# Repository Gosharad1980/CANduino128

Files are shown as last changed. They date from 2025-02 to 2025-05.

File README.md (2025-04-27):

# CANduino128
	- Break-out board pour la carte Olimex AVR-H128-CAN
	- Carte sur base d'AVR AT90CAN128
		- PC104 form factor
		- CAN network
		- SPI
		- I2C
		- bus d'addresse/Data externe via 74AHC373

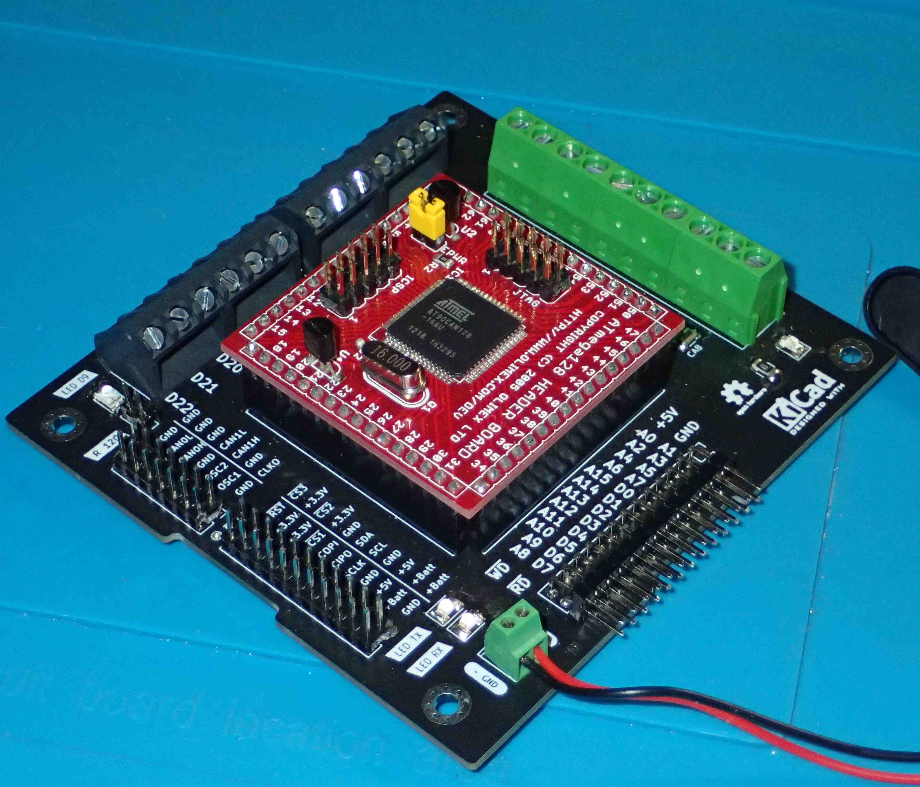
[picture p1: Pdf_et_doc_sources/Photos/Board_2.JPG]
Board 3/4


# Board details
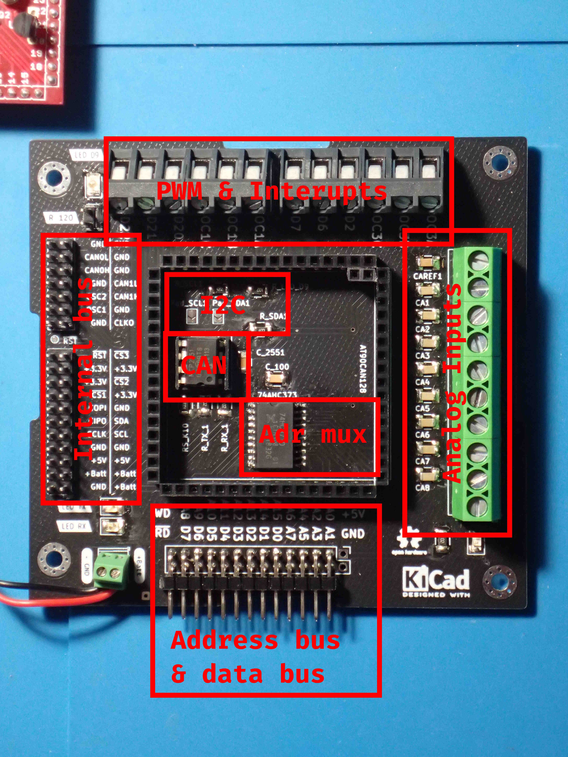
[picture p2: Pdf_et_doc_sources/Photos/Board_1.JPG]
Board details


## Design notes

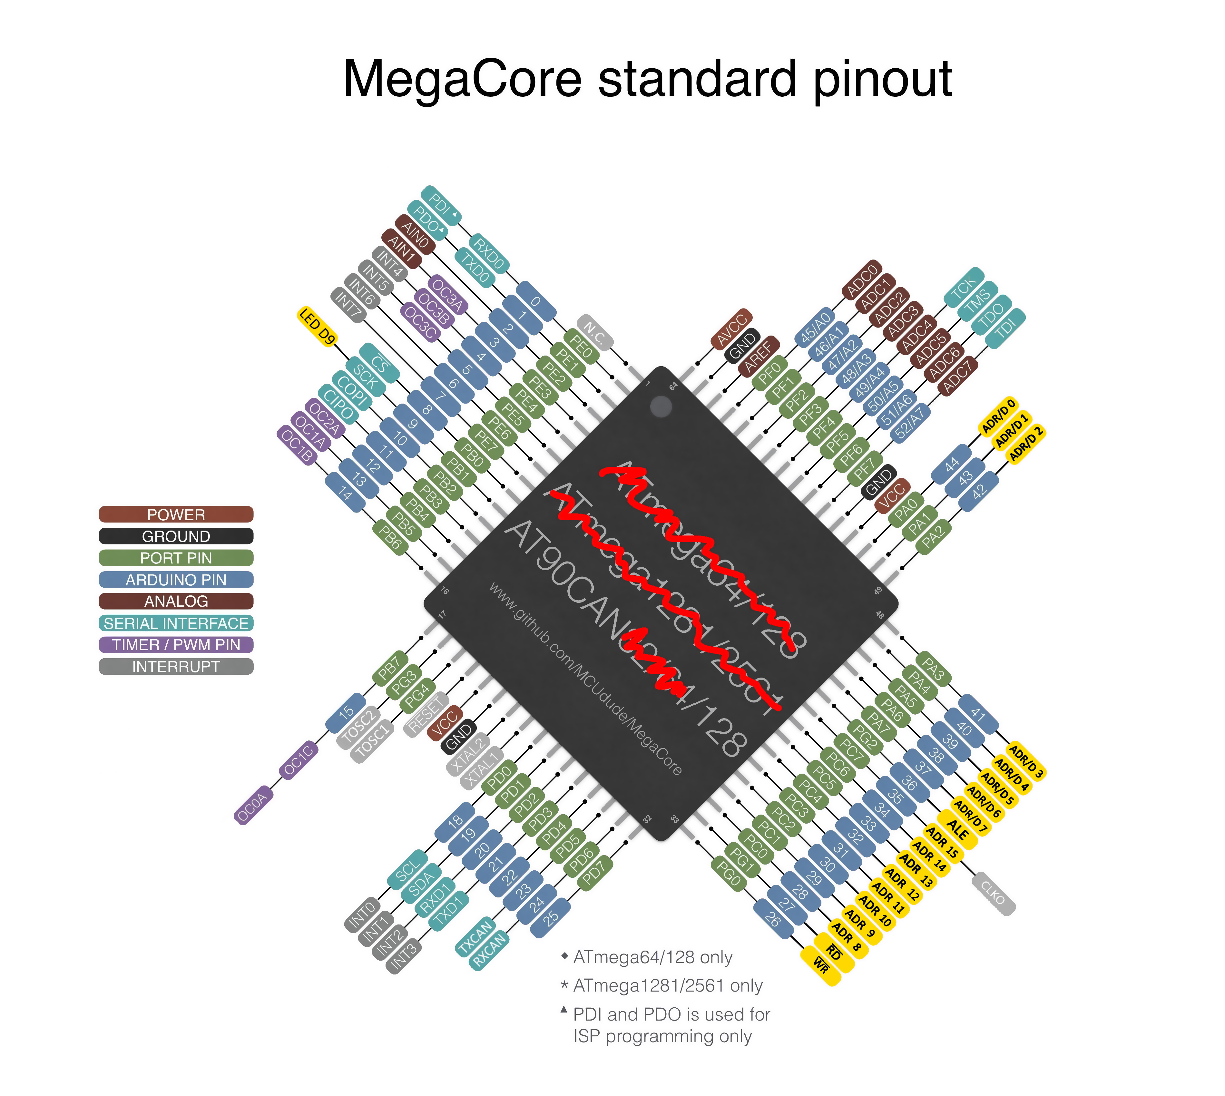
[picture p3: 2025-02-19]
Pdf_et_doc_sources/AT90CANxxx - MegaCore PinOut.jpg

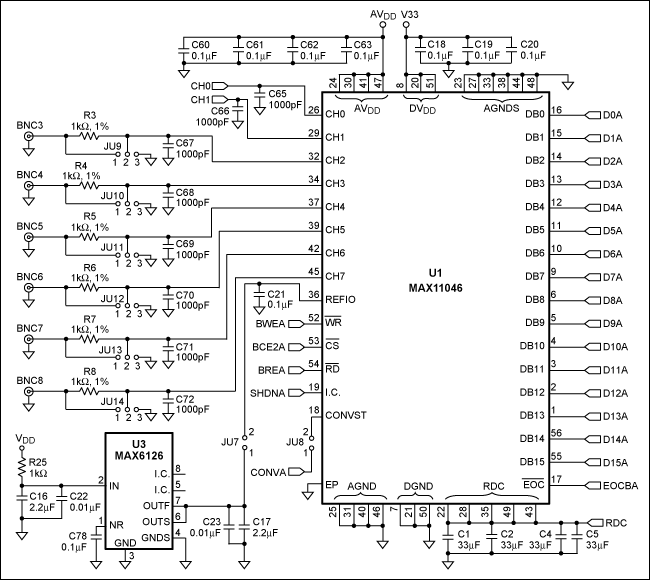
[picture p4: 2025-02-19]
Pdf_et_doc_sources/AT90CAN128 - Application Notes/4359Fig06.gif

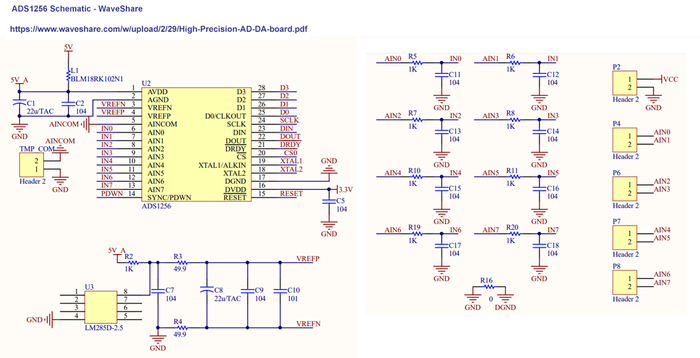
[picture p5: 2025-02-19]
Pdf_et_doc_sources/AT90CAN128 - Application Notes/s3Iia.png

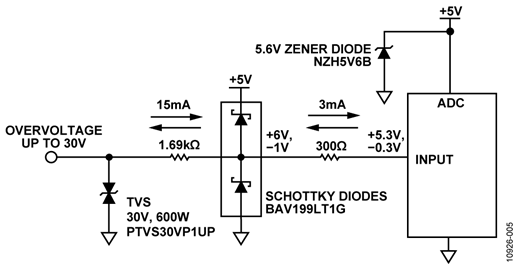
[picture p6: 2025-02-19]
Pdf_et_doc_sources/AT90CAN128 - Application Notes/m8xca9ZTZHjG40SwLESFxN0b7EQkneq3GQtdkflvBjM.png

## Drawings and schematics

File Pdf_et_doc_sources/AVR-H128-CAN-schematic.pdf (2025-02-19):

# Q1 Q²

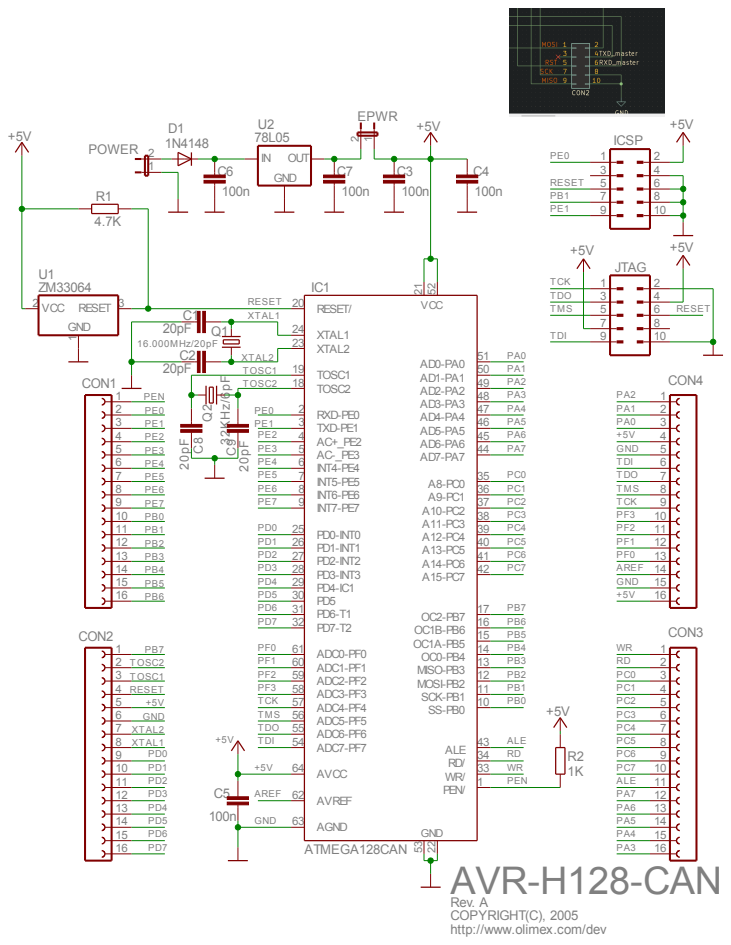
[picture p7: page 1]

Rev. A
COPYRIGHT(C), 2005
http://www.olimex.com/dev

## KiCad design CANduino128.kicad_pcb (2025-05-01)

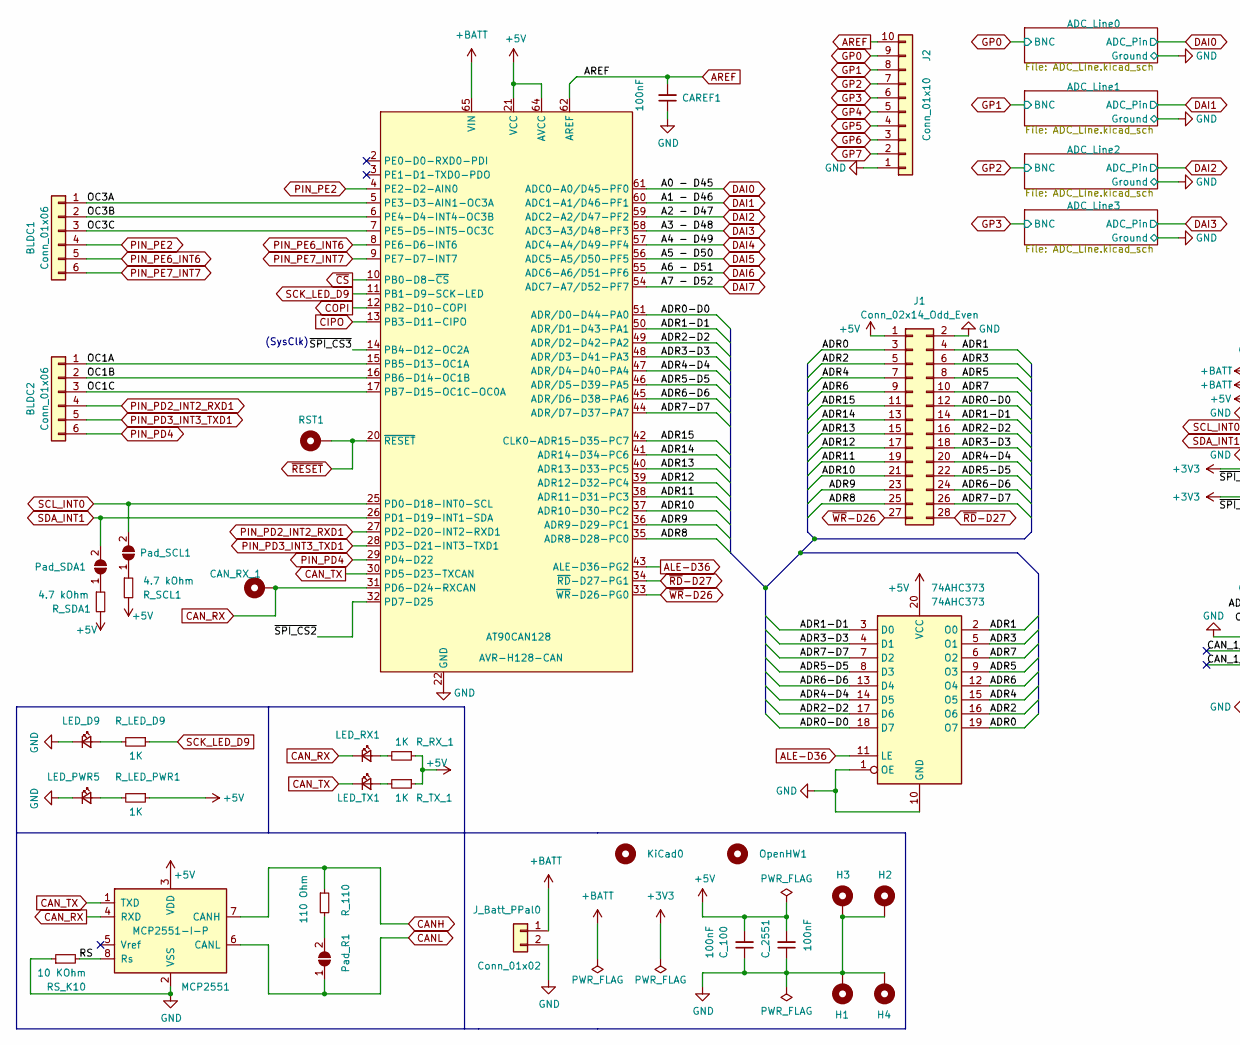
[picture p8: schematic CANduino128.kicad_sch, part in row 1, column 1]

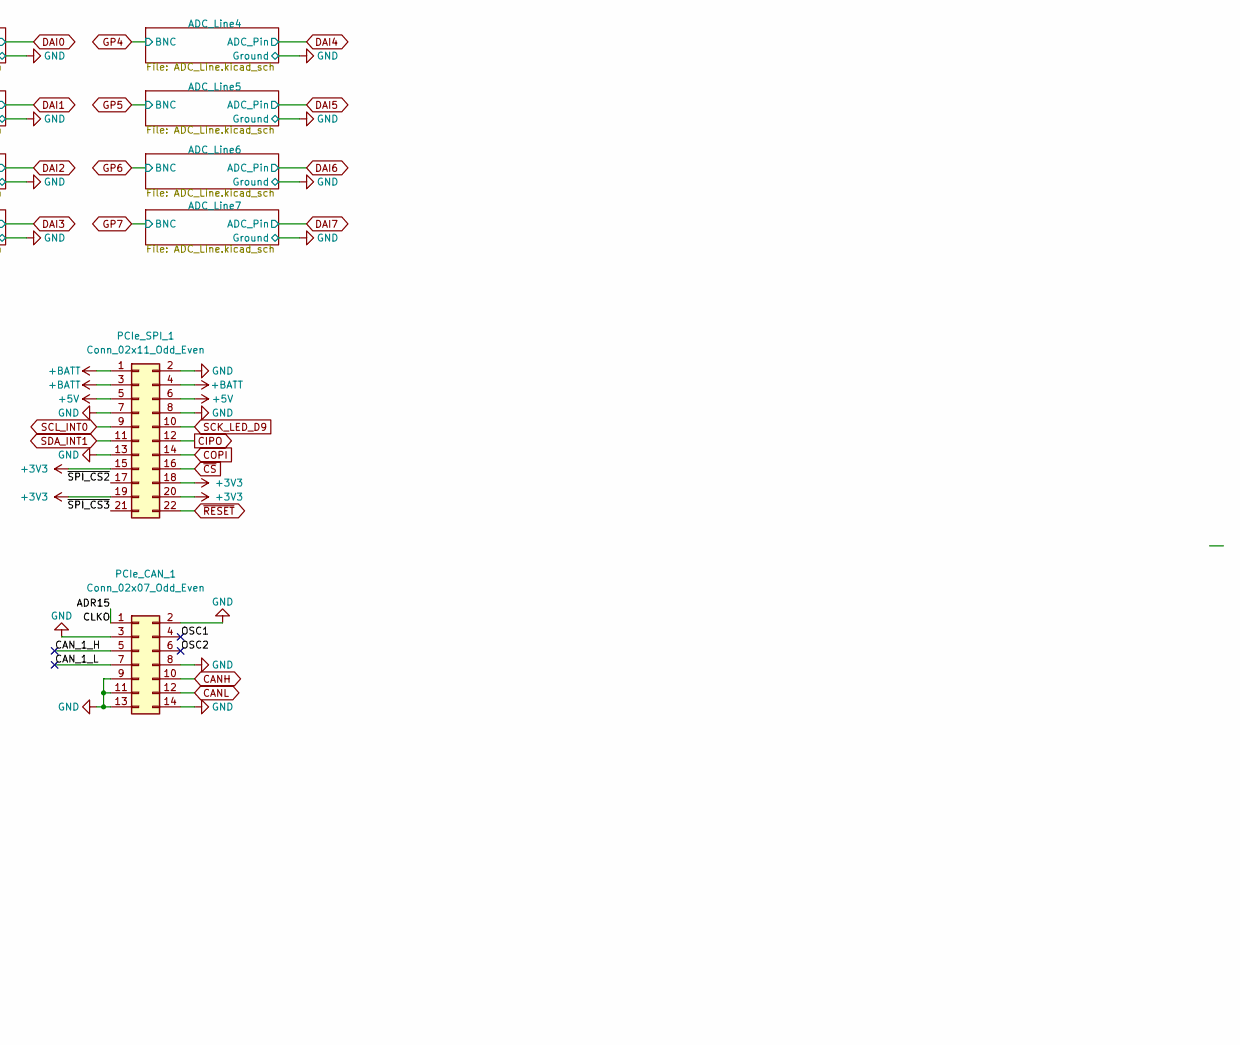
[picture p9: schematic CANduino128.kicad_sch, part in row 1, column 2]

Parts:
74AHC373: 74AHC373; SO-20_12.8x7.5mm_P1.27mm
AT90CAN128: AVR-H128-CAN; AVR_H128-CAN
BLDC1, BLDC2: Conn_01x06; TerminalBlock_Phoenix_MKDS-1,5-6-5.08_1x06_P5.08mm_Horizont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
CAN_RX_1: MountingHole_Pad; SolderWire-0.1sqmm_1x01_D0.4mm_OD1mm
CAREF1: 100nF; C_1210_3225Metric_Pad1.33x2.70mm_HandSolder
C_100, C_2551: 100nF; C_1210_3225Metric_Pad1.33x2.70mm_HandSolder
H1, H2, H3, H4: MountingHole_Pad; MountingHole_3.2mm_M3_Pad_Via
J1: Conn_02x14_Odd_Even; PinHeader_2x14_P2.54mm_Vertical
J2: Conn_01x10; TerminalBlock_Phoenix_MKDS-1,5-10-5.08_1x10_P5.08mm_Horizon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
J_Batt_PPal0: Conn_01x02; TerminalBlock_TE_282834-2_1x02_P2.54mm_Horizontal
KiCad0: MountingHole; KiCad-Logo2_5mm_SilkScreen
LED_D9: LED; LED_1210_3225Metric_Pad1.42x2.65mm_HandSolder
LED_PWR5: LED; LED_1210_3225Metric_Pad1.42x2.65mm_HandSolder
LED_RX1: LED; LED_1210_3225Metric_Pad1.42x2.65mm_HandSolder
LED_TX1: LED; LED_1210_3225Metric_Pad1.42x2.65mm_HandSolder
MCP2551: MCP2551-I-P; DIP-8_W7.62mm_Socket
OpenHW1: MountingHole; OSHW-Logo2_7.3x6mm_SilkScreen
PCIe_CAN_1: Conn_02x07_Odd_Even; PinHeader_2x07_P2.54mm_Vertical
PCIe_SPI_1: Conn_02x11_Odd_Even; PinHeader_2x11_P2.54mm_Vertical
Pad_R1: SolderJumper_2_Open; PinHeader_1x02_P2.54mm_Vertical
Pad_SCL1: SolderJumper_2_Open; SolderJumper-2_P1.3mm_Open_TrianglePad1.0x1.5mm
Pad_SDA1: SolderJumper_2_Open; SolderJumper-2_P1.3mm_Open_TrianglePad1.0x1.5mm
RST1: MountingHole_Pad; TestPoint_Pad_D1.0mm
RS_K10: 10 KOhm; R_1210_3225Metric_Pad1.30x2.65mm_HandSolder
R_110: 110 Ohm; R_1210_3225Metric_Pad1.30x2.65mm_HandSolder
R_LED_D9: 1K; R_1210_3225Metric_Pad1.30x2.65mm_HandSolder
R_LED_PWR1: 1K; R_1210_3225Metric_Pad1.30x2.65mm_HandSolder
R_RX_1: 1K; R_1210_3225Metric_Pad1.30x2.65mm_HandSolder
R_SCL1: 4.7 kOhm; R_1210_3225Metric_Pad1.30x2.65mm_HandSolder
R_SDA1: 4.7 kOhm; R_1210_3225Metric_Pad1.30x2.65mm_HandSolder
R_TX_1: 1K; R_1210_3225Metric_Pad1.30x2.65mm_HandSolder

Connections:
+3V3: PCIe_SPI_1.15, PCIe_SPI_1.18, PCIe_SPI_1.19, PCIe_SPI_1.20
+5V: 74AHC373.20 (VCC), AT90CAN128.21 (VCC), AT90CAN128.52 (VCC), AT90CAN128.64 (AVCC), C_100.2, C_2551.2, J1.1, MCP2551.3 (VDD), PCIe_SPI_1.5, PCIe_SPI_1.6, R_LED_PWR1.1, R_RX_1.1, R_SCL1.2, R_SDA1.2, R_TX_1.1
+BATT: AT90CAN128.65 (VIN), J_Batt_PPal0.1, PCIe_SPI_1.1, PCIe_SPI_1.3, PCIe_SPI_1.4
/ADR0: 74AHC373.19 (O7), J1.3
/ADR0-D0: 74AHC373.18 (D7), AT90CAN128.51 (ADR/D0-D44-PA0), J1.12
/ADR1: 74AHC373.2 (O0), J1.4
/ADR1-D1: 74AHC373.3 (D0), AT90CAN128.50 (ADR/D1-D43-PA1), J1.14
/ADR2: 74AHC373.16 (O6), J1.5
/ADR2-D2: 74AHC373.17 (D6), AT90CAN128.49 (ADR/D2-D42-PA2), J1.16
/ADR3: 74AHC373.5 (O1), J1.6
/ADR3-D3: 74AHC373.4 (D1), AT90CAN128.48 (ADR/D3-D41-PA3), J1.18
/ADR4: 74AHC373.15 (O5), J1.7
/ADR4-D4: 74AHC373.14 (D5), AT90CAN128.47 (ADR/D4-D40-PA4), J1.20
/ADR5: 74AHC373.9 (O3), J1.8
/ADR5-D5: 74AHC373.8 (D3), AT90CAN128.46 (ADR/D5-D39-PA5), J1.22
/ADR6: 74AHC373.12 (O4), J1.9
/ADR6-D6: 74AHC373.13 (D4), AT90CAN128.45 (ADR/D6-D38-PA6), J1.24
/ADR7: 74AHC373.6 (O2), J1.10
/ADR7-D7: 74AHC373.7 (D2), AT90CAN128.44 (ADR/D7-D37-PA7), J1.26
/ADR8: AT90CAN128.35 (ADR8-D28-PC0), J1.25
/ADR9: AT90CAN128.36 (ADR9-D29-PC1), J1.23
/ADR10: AT90CAN128.37 (ADR10-D30-PC2), J1.21
/ADR11: AT90CAN128.38 (ADR11-D31-PC3), J1.19
/ADR12: AT90CAN128.39 (ADR12-D32-PC4), J1.17
/ADR13: AT90CAN128.40 (ADR13-D33-PC5), J1.15
/ADR14: AT90CAN128.41 (ADR14-D34-PC6), J1.13
/ADR15: AT90CAN128.42 (CLK0-ADR15-D35-PC7), J1.11, PCIe_CAN_1.1
/CAN_1_H: PCIe_CAN_1.5
/CAN_1_L: PCIe_CAN_1.7
/OC1A: AT90CAN128.15 (PB5-D13-OC1A), BLDC2.1
/OC1B: AT90CAN128.16 (PB6-D14-OC1B), BLDC2.2
/OC1C: AT90CAN128.17 (PB7-D15-OC1C-OC0A), BLDC2.3
/OC3A: AT90CAN128.5 (PE3-D3-AIN1-OC3A), BLDC1.1
/OC3B: AT90CAN128.6 (PE4-D4-INT4-OC3B), BLDC1.2
/OC3C: AT90CAN128.7 (PE5-D5-INT5-OC3C), BLDC1.3
/OSC1: PCIe_CAN_1.4
/OSC2: PCIe_CAN_1.6
/RS: MCP2551.8 (Rs), RS_K10.2
/~SPI_CS2: AT90CAN128.32 (PD7-D25), PCIe_SPI_1.17
/~SPI_CS3: AT90CAN128.14 (PB4-D12-OC2A), PCIe_SPI_1.21
ALE-D36: 74AHC373.11 (LE), AT90CAN128.43 (ALE-D36-PG2)
AREF: AT90CAN128.62 (AREF), CAREF1.2, J2.10
CANH: MCP2551.7 (CANH), PCIe_CAN_1.10, R_110.1
CANL: MCP2551.6 (CANL), PCIe_CAN_1.12, Pad_R1.1 (A)
CAN_RX: AT90CAN128.31 (PD6-D24-RXCAN), CAN_RX_1.1, LED_RX1.1 (K), MCP2551.4 (RXD)
CAN_TX: AT90CAN128.30 (PD5-D23-TXCAN), LED_TX1.1 (K), MCP2551.1 (TXD)
CIPO: AT90CAN128.13 (PB3-D11-CIPO), PCIe_SPI_1.12
COPI: AT90CAN128.12 (PB2-D10-COPI), PCIe_SPI_1.14
DAI0: AT90CAN128.61 (ADC0-A0/D45-PF0); also elsewhere on the board
DAI1: AT90CAN128.60 (ADC1-A1/D46-PF1); also elsewhere on the board
DAI2: AT90CAN128.59 (ADC2-A2/D47-PF2); also elsewhere on the board
DAI3: AT90CAN128.58 (ADC3-A3/D48-PF3); also elsewhere on the board
DAI4: AT90CAN128.57 (ADC4-A4/D49-PF4); also elsewhere on the board
DAI5: AT90CAN128.56 (ADC5-A5/D50-PF5); also elsewhere on the board
DAI6: AT90CAN128.55 (ADC6-A6/D51-PF6); also elsewhere on the board
DAI7: AT90CAN128.54 (ADC7-A7/D52-PF7); also elsewhere on the board
GND: 74AHC373.1 (OE), 74AHC373.10 (GND), AT90CAN128.22 (GND), AT90CAN128.53 (GND), AT90CAN128.63 (GND), AT90CAN128.66 (PWRGND), CAREF1.1, C_100.1, C_2551.1, H1.1, H2.1, H3.1, H4.1, J1.2, J2.1, J_Batt_PPal0.2, LED_D9.1 (K), LED_PWR5.1 (K), MCP2551.2 (VSS), PCIe_CAN_1.2, PCIe_CAN_1.3, PCIe_CAN_1.8, PCIe_CAN_1.9, PCIe_CAN_1.11, PCIe_CAN_1.13, PCIe_CAN_1.14, PCIe_SPI_1.2, PCIe_SPI_1.7, PCIe_SPI_1.8, PCIe_SPI_1.13, RS_K10.1; also elsewhere on the board
GP0: J2.9; also elsewhere on the board
GP1: J2.8; also elsewhere on the board
GP2: J2.7; also elsewhere on the board
GP3: J2.6; also elsewhere on the board
GP4: J2.5; also elsewhere on the board
GP5: J2.4; also elsewhere on the board
GP6: J2.3; also elsewhere on the board
GP7: J2.2; also elsewhere on the board
unnamed: LED_D9.2 (A), R_LED_D9.2
unnamed: LED_PWR5.2 (A), R_LED_PWR1.2
unnamed: LED_RX1.2 (A), R_RX_1.2
unnamed: LED_TX1.2 (A), R_TX_1.2
unnamed: Pad_R1.2 (B), R_110.2
unnamed: Pad_SCL1.1 (A), R_SCL1.1
unnamed: Pad_SDA1.1 (A), R_SDA1.1
PIN_PD2_INT2_RXD1: AT90CAN128.27 (PD2-D20-INT2-RXD1), BLDC2.4
PIN_PD3_INT3_TXD1: AT90CAN128.28 (PD3-D21-INT3-TXD1), BLDC2.5
PIN_PD4: AT90CAN128.29 (PD4-D22), BLDC2.6
PIN_PE2: AT90CAN128.4 (PE2-D2-AIN0), BLDC1.4
PIN_PE6_INT6: AT90CAN128.8 (PE6-D6-INT6), BLDC1.5
PIN_PE7_INT7: AT90CAN128.9 (PE7-D7-INT7), BLDC1.6
SCK_LED_D9: AT90CAN128.11 (PB1-D9-SCK-LED), PCIe_SPI_1.10, R_LED_D9.1
SCL_INT0: AT90CAN128.25 (PD0-D18-INT0-SCL), PCIe_SPI_1.9, Pad_SCL1.2 (B)
SDA_INT1: AT90CAN128.26 (PD1-D19-INT1-SDA), PCIe_SPI_1.11, Pad_SDA1.2 (B)
~CS: AT90CAN128.10 (PB0-D8-~CS), PCIe_SPI_1.16
~RD-D27: AT90CAN128.34 (~RD-D27-PG1), J1.28
~RESET: AT90CAN128.20 (~RESET), PCIe_SPI_1.22, RST1.1
~WR-D26: AT90CAN128.33 (~WR-D26-PG0), J1.27

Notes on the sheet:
(SysClk)

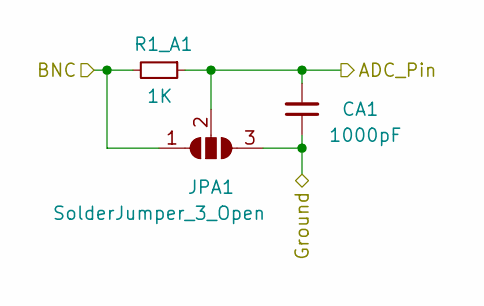
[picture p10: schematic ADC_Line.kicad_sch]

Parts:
CA1: 1000pF; C_1210_3225Metric_Pad1.33x2.70mm_HandSolder
JPA1: SolderJumper_3_Open; SolderJumper-3_P1.3mm_Open_RoundedPad1.0x1.5mm
R1_A1: 1K; R_1210_3225Metric_Pad1.30x2.65mm_HandSolder

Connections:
DAI0: CA1.2, JPA1.2 (C), R1_A1.1; also elsewhere on the board
GND: CA1.1, JPA1.3 (B); also elsewhere on the board
GP0: JPA1.1 (A), R1_A1.2; also elsewhere on the board

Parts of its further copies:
CA2, CA3, CA4, CA5, CA6, CA7, CA8: 1000pF; C_1210_3225Metric_Pad1.33x2.70mm_HandSolder
JPA2, JPA3, JPA4, JPA5, JPA6, JPA7, JPA8: SolderJumper_3_Open; SolderJumper-3_P1.3mm_Open_RoundedPad1.0x1.5mm
R1_A2, R1_A3, R1_A4, R1_A5, R1_A6, R1_A7, R1_A8: 1K; R_1210_3225Metric_Pad1.30x2.65mm_HandSolder

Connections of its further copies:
DAI1: CA2.2, JPA2.2 (C), R1_A2.1; also elsewhere on the board
DAI2: CA3.2, JPA3.2 (C), R1_A3.1; also elsewhere on the board
DAI3: CA4.2, JPA4.2 (C), R1_A4.1; also elsewhere on the board
DAI4: CA5.2, JPA5.2 (C), R1_A5.1; also elsewhere on the board
DAI5: CA6.2, JPA6.2 (C), R1_A6.1; also elsewhere on the board
DAI6: CA7.2, JPA7.2 (C), R1_A7.1; also elsewhere on the board
DAI7: CA8.2, JPA8.2 (C), R1_A8.1; also elsewhere on the board
GND: CA2.1, CA3.1, CA4.1, CA5.1, CA6.1, CA7.1, CA8.1, JPA2.3 (B), JPA3.3 (B), JPA4.3 (B), JPA5.3 (B), JPA6.3 (B), JPA7.3 (B), JPA8.3 (B); also elsewhere on the board
GP1: JPA2.1 (A), R1_A2.2; also elsewhere on the board
GP2: JPA3.1 (A), R1_A3.2; also elsewhere on the board
GP3: JPA4.1 (A), R1_A4.2; also elsewhere on the board
GP4: JPA5.1 (A), R1_A5.2; also elsewhere on the board
GP5: JPA6.1 (A), R1_A6.2; also elsewhere on the board
GP6: JPA7.1 (A), R1_A7.2; also elsewhere on the board
GP7: JPA8.1 (A), R1_A8.2; also elsewhere on the board

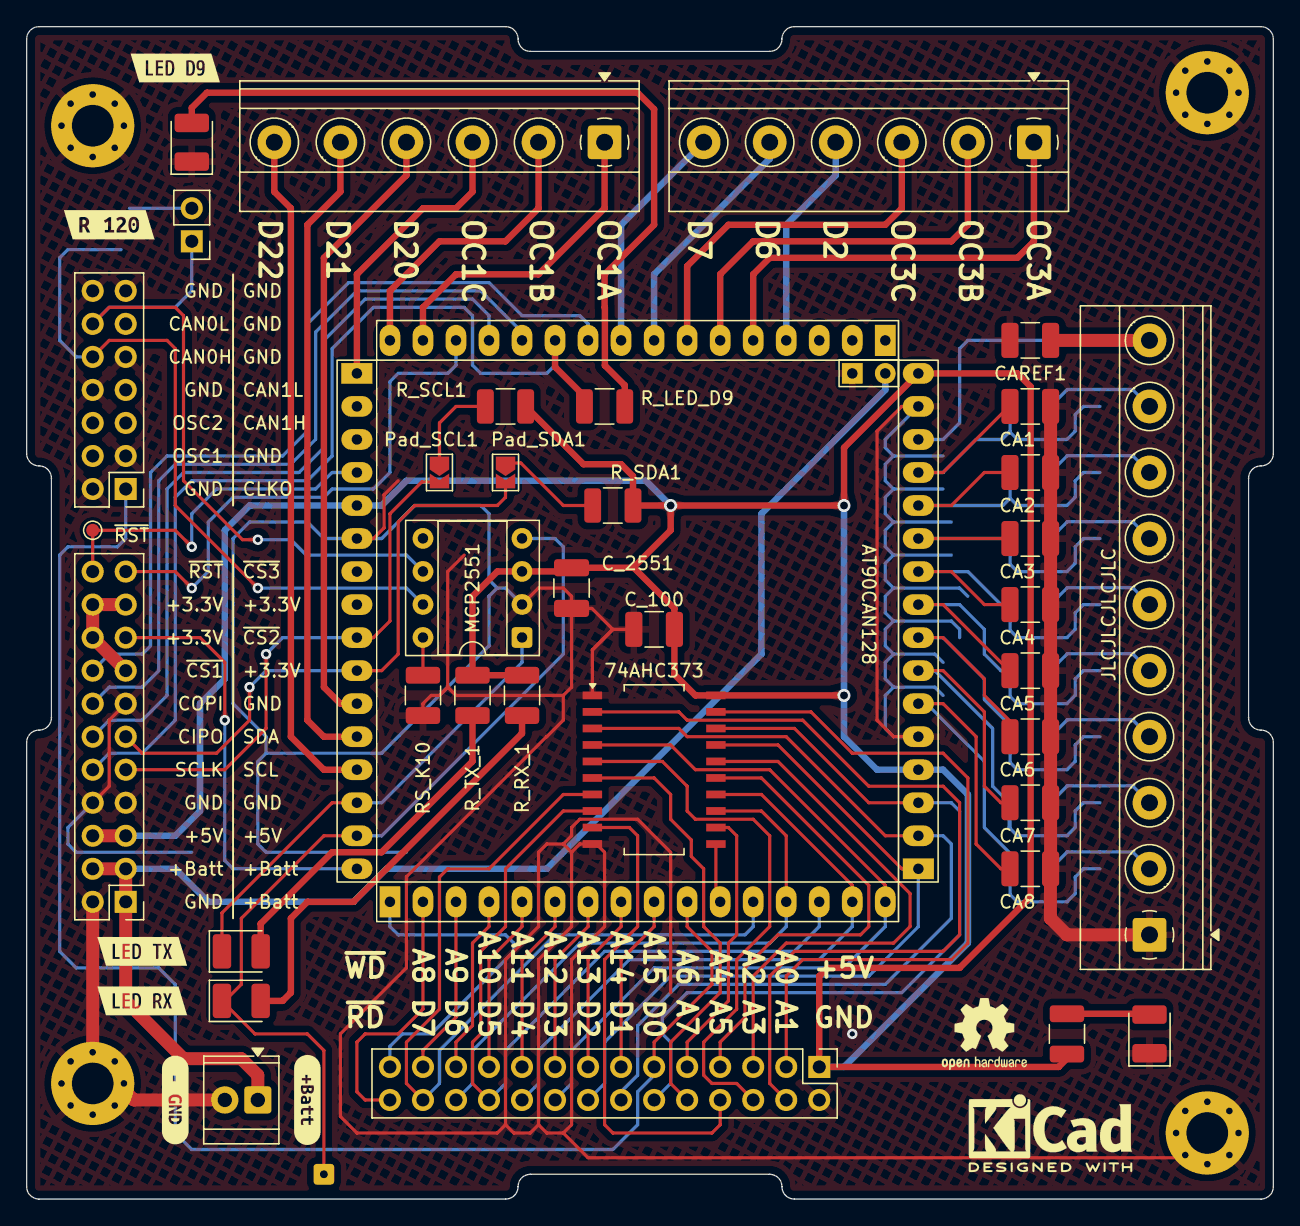
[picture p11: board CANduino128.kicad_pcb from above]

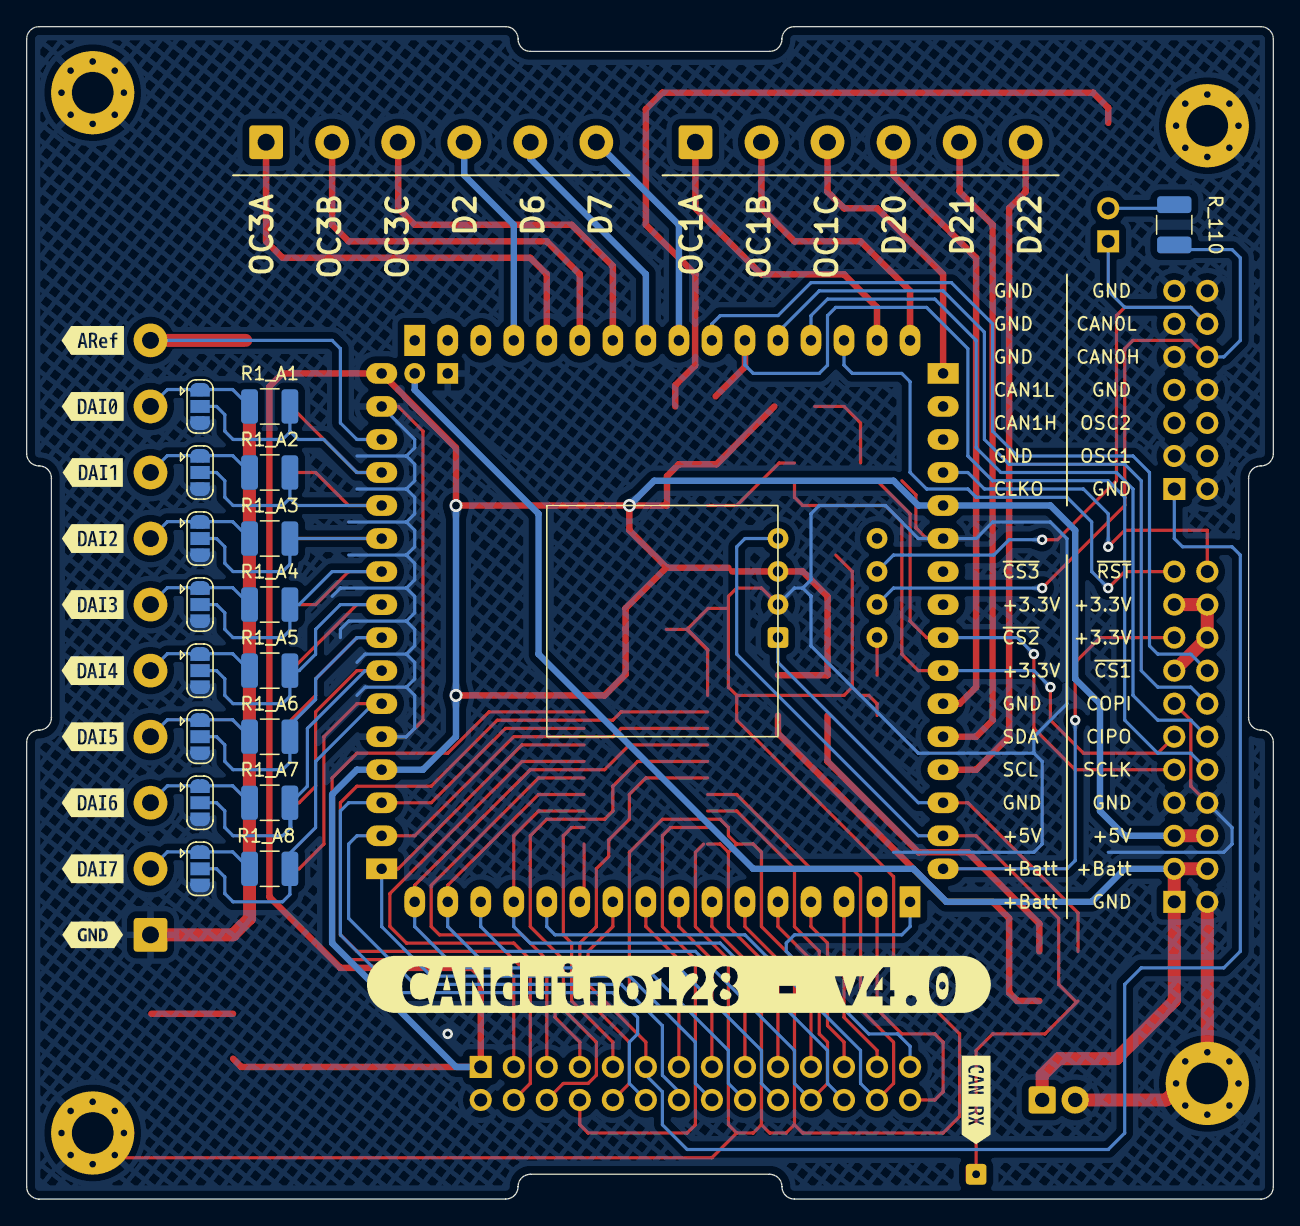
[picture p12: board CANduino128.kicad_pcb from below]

Board: 2 copper layers, 95.9 x 90.2 mm, 78 parts (29 on the bottom side), 81 nets.

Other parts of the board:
kibuzzard-62F694D7: G***; kibuzzard-62F694D7
kibuzzard-62F83662: G***; kibuzzard-62F83662
kibuzzard-638A835C: G***; kibuzzard-638A835C
kibuzzard-6252DD85: G***; kibuzzard-6252DD85
kibuzzard-6252DDA8: G***; kibuzzard-6252DDA8
kibuzzard-6252E5C3: G***; kibuzzard-6252E5C3
kibuzzard-62533B1F: G***; kibuzzard-62533B1F
kibuzzard-62799BC1: G***; kibuzzard-62799BC1
kibuzzard-638672AD: G***; kibuzzard-638672AD
kibuzzard-6315171A: G***; kibuzzard-6315171A
kibuzzard-6315172E: G***; kibuzzard-6315172E
kibuzzard-6315173E: G***; kibuzzard-6315173E
kibuzzard-63151701: G***; kibuzzard-63151701
kibuzzard-63151724: G***; kibuzzard-63151724
kibuzzard-63151737: G***; kibuzzard-63151737
kibuzzard-63151748: G***; kibuzzard-63151748
kibuzzard-63151750: G***; kibuzzard-63151750
kibuzzard-63867289: G***; kibuzzard-63867289

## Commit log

2022-08-07 Allez, on se fait une PC104 (ou autre, on verra) avec un bus custom (parce que le bus ISA c'est pas glop en terme de routage) !
2022-08-12 Ha ha ! Probablement un lancement en production. En tout cas à 99%. - quelques replacement de Pad - correction de Silkscreen
    [CANduino128-B_Cu.gbl, CANduino128-B_Mask.gbs, CANduino128-B_Paste.gbp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]
2022-08-14 A envoyer en prod. - câblage Reset (avec "via") - câblage T0_0C0x - câblage ICP1 - correction silskreen
    [CANduino128-B_Cu.gbl, CANduino128-B_Mask.gbs, CANduino128-B_Paste.gbp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]
2022-08-23 Dernier run DRC pour production :)
    [CANduino128-B_Cu.gbl, CANduino128-B_Mask.gbs, CANduino128-B_Paste.gbp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]
2022-11-22 Allez on entame les travaux ... et y'a du taf.
    [CANduino128.kicad_sch]
2022-11-27 Houlà ! On y est presque ! Un peu de silkscreen à mettre à jour et on aura une révision livrable.
    [CANduino128-B_Cu.gbl, CANduino128-B_Mask.gbs, CANduino128-B_Paste.gbp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]
2022-11-27 Bin ouais, y'a changement d'interfaçage avec le monde extérieure ... puisqu'on change de form-factor.
2022-11-29 Silkscreen terminé. Bon pour release après une dernière vérif.
    [CANduino128.kicad_sch]
2022-12-02 Avec les réglages "Rancunes"
    [CANduino128-B_Cu.gbl, CANduino128-B_Mask.gbs, CANduino128-B_Paste.gbp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]
2023-03-27 KiCad 7.0 SPI_CS3 Reste simplification du chemin Redondance alim +5V
    Mais surtout KiCad 7.0 qui empêche la rétrocompatibilité avec les version antérieure sous KiCad 6.x
    [ADC_Line.kicad_sch, CANduino128.kicad_sch]
2023-04-01 Petites correction de GND qui étaient des "Oval" et non pas des "Circular"
2023-04-02 Régénération du plan de masse Création des Gerber
    [CANduino128-B_Cu.gbl, CANduino128-B_Mask.gbs, CANduino128-B_Paste.gbp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]
2023-04-03 Elargissement des pistes d'alim de 0.25mm à 0.5mm Application de règles d'un prof random sur internet Régénération des fichiers gerber
    [CANduino128-B_Cu.gbl, CANduino128-B_Mask.gbs, CANduino128-B_Paste.gbp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]
2023-04-17 Mise à jour du DRC ... argh.
    [CANduino128-B_Cu.gbl, CANduino128-B_Mask.gbs, CANduino128-B_Paste.gbp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]
2023-04-29 Mini update du routage de +Batt et +5V
    [CANduino128-B_Cu.gbl, CANduino128-B_Mask.gbs, CANduino128-B_Paste.gbp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]
2023-05-23 "Correction" du bug sur les nombres à plus de chiffres significatifs sur les plans de masse Ajout des teardrops
    [CANduino128-B_Cu.gbl, CANduino128-B_Mask.gbs, CANduino128-B_Paste.gbp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]
2023-05-23 Ajout du marquage JLCJLCJLCJLC
    [CANduino128-B_Cu.gbl, CANduino128-B_Mask.gbs, CANduino128-B_Paste.gbp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]
2023-06-14 Régen de la BOM pour le soudage des composants.
2023-08-18 Correction clearance de bord de carte à 0.635mm
2025-02-19 Passage à KiCad 9.0 RC1
    [ADC_Line.kicad_sch, BOM.ods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]
2025-02-19 Ajout des docs Pdf
2025-05-01 3D models update
    [ADC_Line.kicad_sch, CANduino128.kicad_pcb, CANduino128.kicad_sch]
2025-05-01 Package3D model list update
    [CANduino128.kicad_pcb]
2026-08-29 Update : doc + gerber files - add schematics.pdf file - generate gerber files
2026-09-26 [UPGRADE] : Changement de bus interne de communication (pas de rétrocompatibilité) - remplacement du connecteur double par un seul connecteur IDE 40pin - rerouting léger
2026-09-26 [update] : mise à jour du schematics.pdf
2026-09-27 [UPGRADE] : OC2A sur OSC1 + suppression des vias
2026-11-07 update : bom/ibom.html
